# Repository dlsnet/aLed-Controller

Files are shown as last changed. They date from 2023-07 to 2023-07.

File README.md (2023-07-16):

# aLed Controller

aLed Controller is an analog leds controller for the smart home. It was designed to run with Home Assistant using ESPHome and features:

-  Six analog channels. (Can run a single CCTRGB or RGBW strip, up to two RGB strips, up to three CCT strips, or up to six single color strips with a high current and high PWM frequencies).
- Based on ESP32-WROOM-32.
- Runs EPSHome (or you can flash it with whatever firmware makes you happy)
- Changeable fuse
- [Optional] INA226 sensor (a current shunt and power monitor).
- [Optional] Ambient light sensor.
- [Optional] PCB temperature sensor (can be handy if you plan to run a high power load).
- [Optional] SHT40 temperature and humidity sensor.
- [Optional] DS18B20 temperature sensor (cheaper, easier to get hold of, and solder compared to SHT40).
- [Optional] Outputs for up to 3 external buttons.
- [Optional] I2C bus output for plugging an external sensor.
- [Optional] Connector for ePaper display.

The controller works with 5-24v input. Positive output lines are protected by a replaceable fuse.

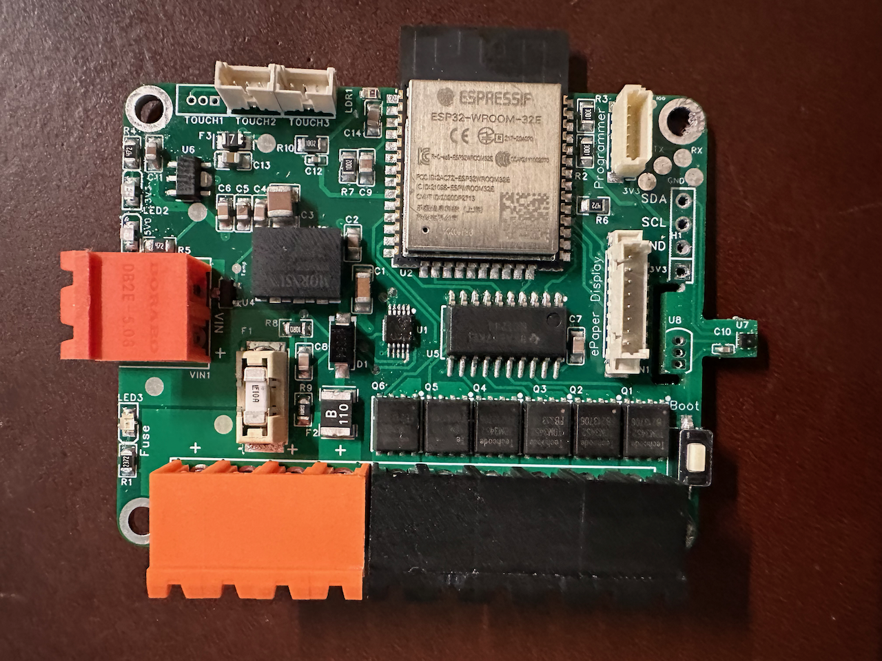
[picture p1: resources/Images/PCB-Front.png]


## PCB ordering

If you want to support the project, you can order PCB manufacturing and/or assembly on PCBWay

- [PCBWay Order](https://www.pcbway.com/project/shareproject/aLed_Controller_v2_4e3c079f.html) - they do quite necelly. Please keep in mind that stencil will be very handy.

<p align="center">
<a href="https://www.pcbway.com/project/shareproject/aLed_Controller_v2_4e3c079f.html">PCB from PCBWay</a>
  
</p>

## Enclosure

3D printed enclosure is available for the PCB. STL files can be found [here](https://github.com/dlsnet/aLed-Controller/tree/main/resources/Case%20STL)

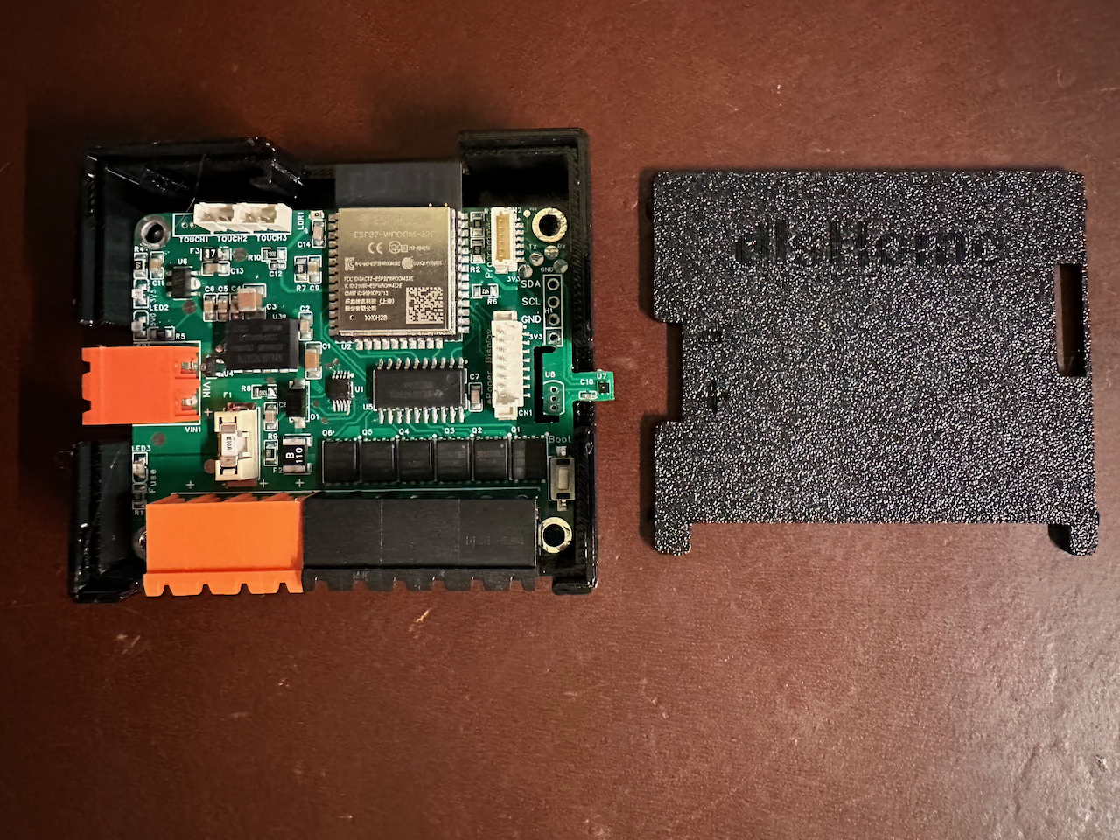
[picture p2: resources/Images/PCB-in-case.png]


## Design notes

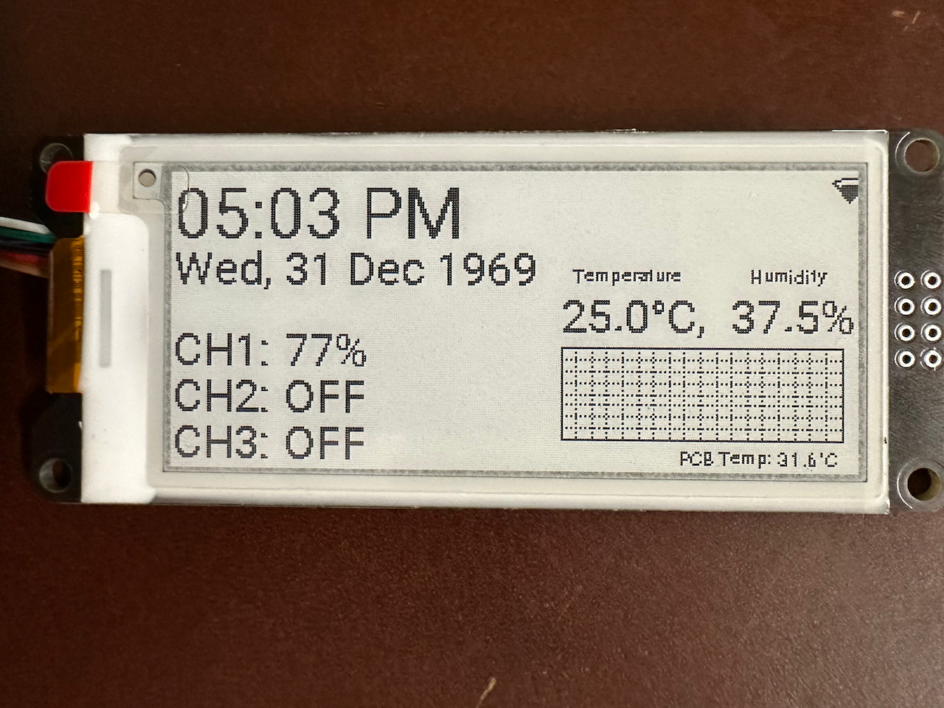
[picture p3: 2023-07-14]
resources/Images/ePaper-Display.png

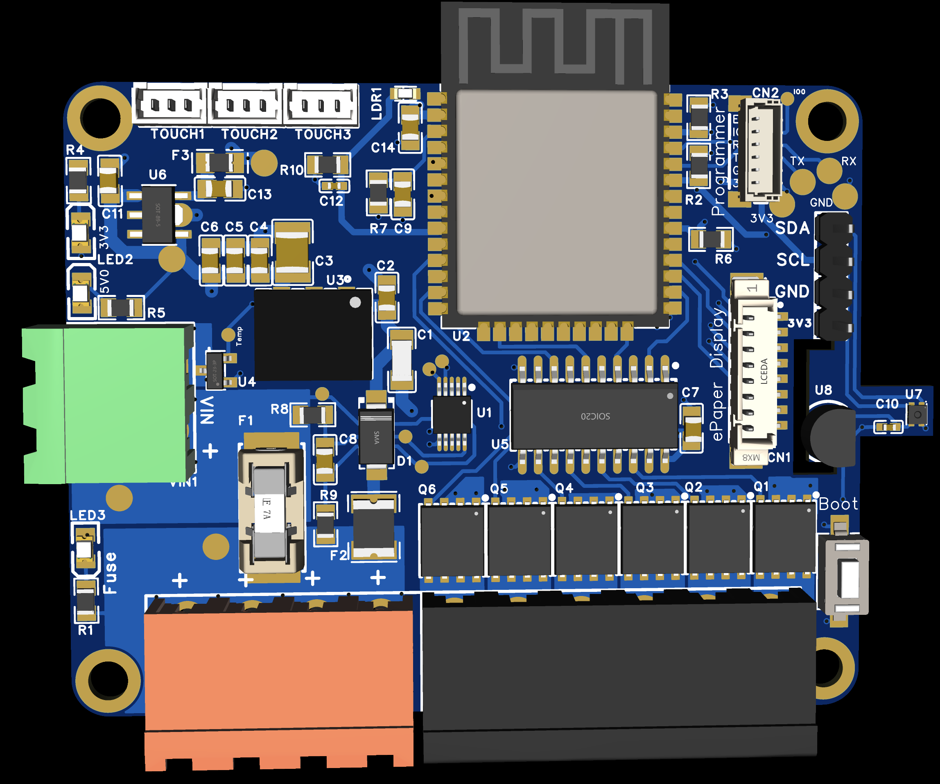
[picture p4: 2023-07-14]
resources/Images/PCB-Render-Front.png

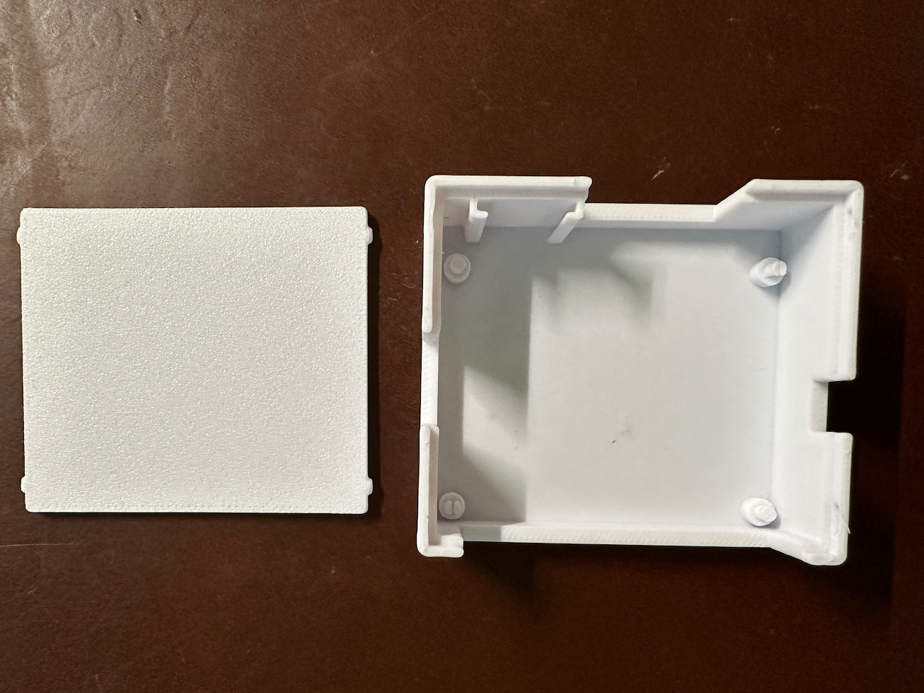
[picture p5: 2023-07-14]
resources/Images/Case.png

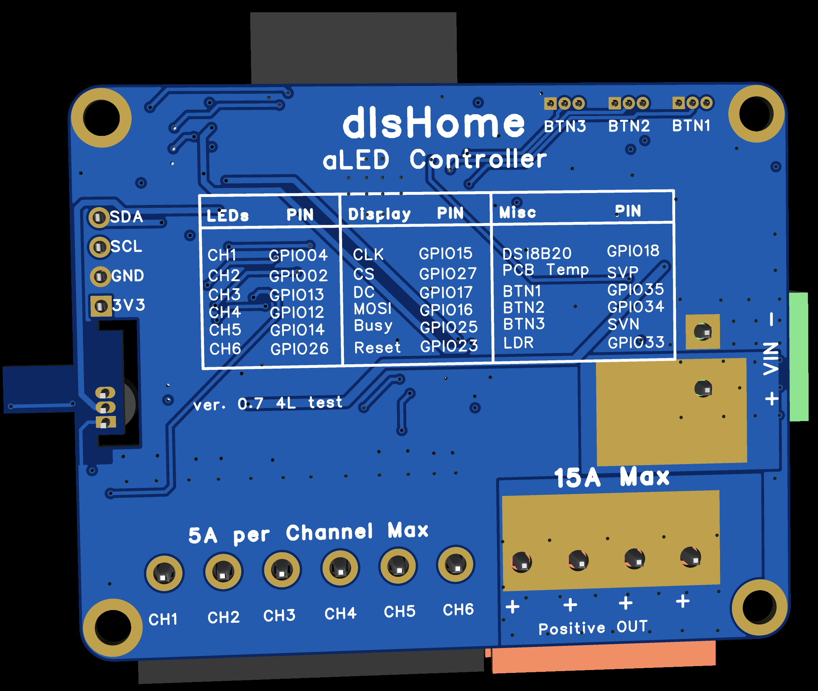
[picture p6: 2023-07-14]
resources/Images/PCB-Render-Back.png

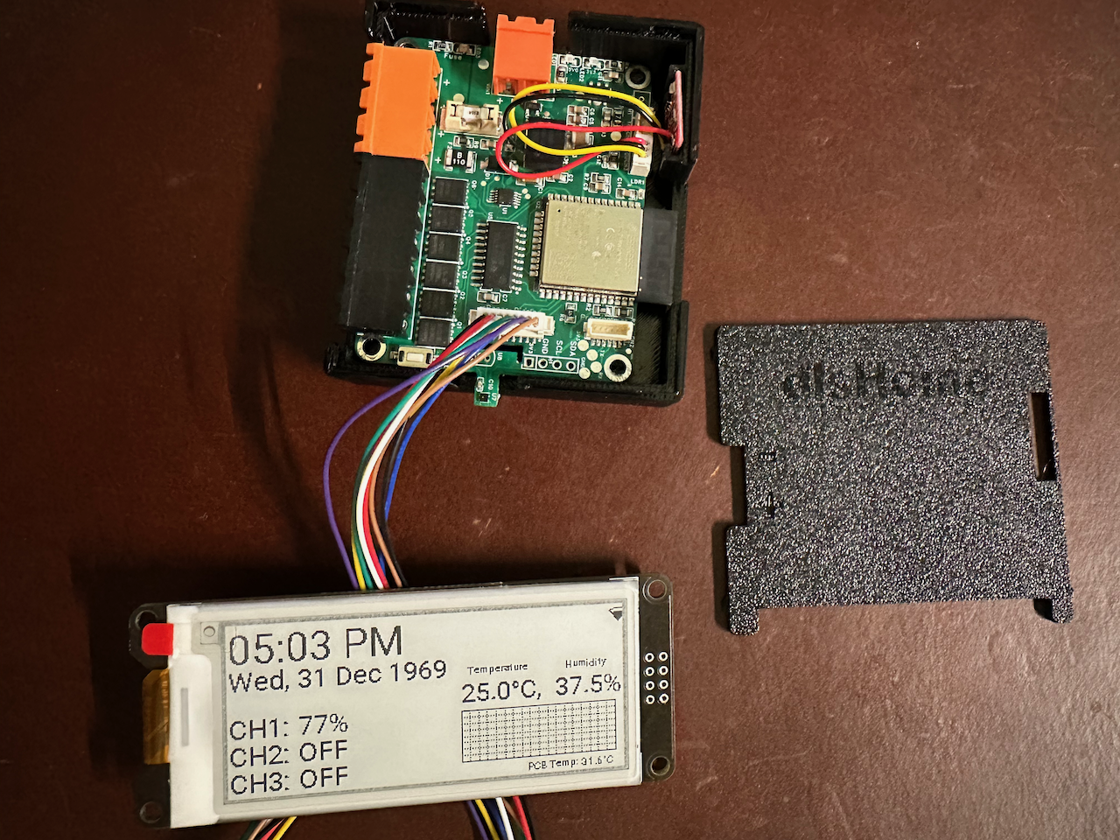
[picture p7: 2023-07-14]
resources/Images/Full-Set.png

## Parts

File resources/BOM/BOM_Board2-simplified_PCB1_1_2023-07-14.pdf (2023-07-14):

No. | Quantity | Comment | Designator | Footprint | Manufacturer Part | Supplier Part | Supplier
1 | 1 | 10uF | C1 | C1206 | CL31B106KBHNNNE | C89632 | LCSC
2 | 5 | 100nF | C2,C4,C7,C8,C14 | C0805 | TCC0805X7R104K500DT | C282732 | LCSC
3 | 1 | 47uF | C3 | C1210 | GRM32ER71A476KE15L | C84494 | LCSC
4 | 1 | 10nF | C5 | C0805 | TCC0805X7R103K500DT | C282728 | LCSC
5 | 1 | 1nF | C6 | C0805 | TCC0805X7R102M500DT C713510 | | LCSC
6 | 1 | 1uF | C9 | C0805 | CL21B105KBFNNNE | C28323 | LCSC
7 | 2 | 100nF | C10,C12 | C0402 | TCC0402X7R104K160AT | C392963 | LCSC
8 | 2 | 10uF | C11,C13 | C0805 | CL21A106KPFNNNE | C17024 | LCSC
9 | 1 | AFC12-S08CCC-00 | CN1 | CONN-SMD_8P-P1.25-V-M_AFC12-S08CCC-00AFC12-S08CCC-00 | | C395349 | LCSC
10 | 1 | JST 1mm | CN2 | CONN-SMD-6P-P1.00_BM06B-SRSS-TB-LF-SN JST 1mm | | C160392 | LCSC
11 | 1 | SS54 | D1 | SMA_L4.4-W2.8-LS5.4-R-RD | SS54 | C513478 | LCSC
12 | 1 | 01550900M | F1 | FUSE-SMD_L9.8-W5.0 | 01550900M | C108518 | LCSC
13 | 1 | BSMD1812-110-33V | F2 | F1812 | BSMD1812-110-33V | C883150 | LCSC
14 | 1 | ASMD0805-075 | F3 | F0805 | ASMD0805-075 | C135330 | LCSC
15 | 1 | OUTG | GNDOUT1 | CONN-TH_6P-P5.08_DB2ER-5.08-6P-BK | OUTG | C430467 | LCSC
16 | 1 | HDR2.54-LI-2x4P | H1 | HDR-TH_4P-P2.54-V-M | HDR2.54-LI-2x4P | C9900020145 | LCSC
17 | 1 | ALS-PT19-315C/L177/TR8 | LDR1 | SENSORS-SMD_ALS-PT19 | ALS-PT19-315C/L177/TR8 C146233 | | LCSC
18 | 1 | Power LED | LED1 | LED0805-R-RD | NCD0805O1 | C84262 | LCSC
19 | 1 | 3.3 LED | LED2 | LED0805-R-RD | NCD0805O1 | C84262 | LCSC
20 | 1 | Fuse LED | LED3 | LED0805-R-RD | NCD0805O1 | C84262 | LCSC
21 | 6 | TDM3452 | Q1,Q2,Q3,Q4,Q5,Q6 | DFN-8_L5.7-W5.1-P1.27-LS6.1-BL-2 | TDM3452 | C380223 | LCSC
22 | 1 | 23.7K | R1 | R0805 | 23.7K | C17564 | LCSC
23 | 2 | 3kΩ | R2,R3 | R0805 | 0805W8F3001T5E | C17661 | LCSC
24 | 3 | 4.7kΩ | R4,R5,R6 | R0805 | 0805W8F4701T5E | C17673 | LCSC
25 | 2 | 10kΩ | R7,R10 | R0805 | 0805W8F1002T5E | C17414 | LCSC
26 | 2 | 10Ω | R8,R9 | R0805_NEW | 0805W8F100JT5E | C17415 | LCSC
27 | 1 | Boot | SW1 | SW-SMD_L6.0-W3.5-LS8.0 | Boot | C2888456 | LCSC
28 | 1 | Touch 1 | TOUCH1 | CONN-TH_3P-P1.25_CAX_1.25-3A | Touch 1 | C722597 | LCSC
29 | 1 | Touch 2 | TOUCH2 | CONN-TH_3P-P1.25_CAX_1.25-3A | Touch 2 | C722597 | LCSC
30 | 1 | Touch 3 | TOUCH3 | CONN-TH_3P-P1.25_CAX_1.25-3A | Touch 3 | C722597 | LCSC
31 | 1 | INA226AIDGSR | U1 | MSOP-10_L3.0-W3.0-P0.50-LS5.0-BL-dla | INA226AIDGSR | C49851 | LCSC
32 | 1 | ESP32-WROOM-32E-N8 | U2 | WIFI-SMD_ESP32-WROOM-32E | ESP32-WROOM-32E-N8 | C701342 | LCSC
33 | 1 | K7805MT-1000R4 | U3 | PWRM-SMD_K78XXMT-1000R4 | K7805MT-1000R4 | C2692189 | LCSC
34 | 1 | MCP9700AT-E/TT | U4 | SOT-23-3_L2.9-W1.3-P1.90-LS2.4-BR | MCP9700AT-E/TT | C127949 | LCSC
35 | 1 | SN74HCT244NSR | U5 | SOIC-20_L13.3-W5.5-P1.27-LS7.8-BL | SN74HCT244NSR | C6777 | LCSC
36 | 1 | ME6217C33P5G | U6 | SOT-89-5_L4.5-W2.5-P1.50-LS4.5-BR | ME6217C33P5G | C81592 | LCSC
37 | 1 | SHT40-AD1B-R2 | U7 | DFN-4_L1.5-W1.5-P0.8-TL-EP-dls | SHT40-AD1B-R2 | C2909890 | LCSC
38 | 1 | DS18B20 | U8 | TO-92-3_L4.9-W3.7-P1.27-L | DS18B20 | C376006 | LCSC
39 | 1 | LINE IN | VIN1 | CONN-TH_2P-P5.08_XY2500R-D5.08-2P | XY2500R-D-5.08-2P | C505824 | LCSC
40 | 1 | OUT | VINOUT1 | CONN-TH_4P-P5.08_DB2ER-5.08-4P-OG | OUT | C430449 | LCSC

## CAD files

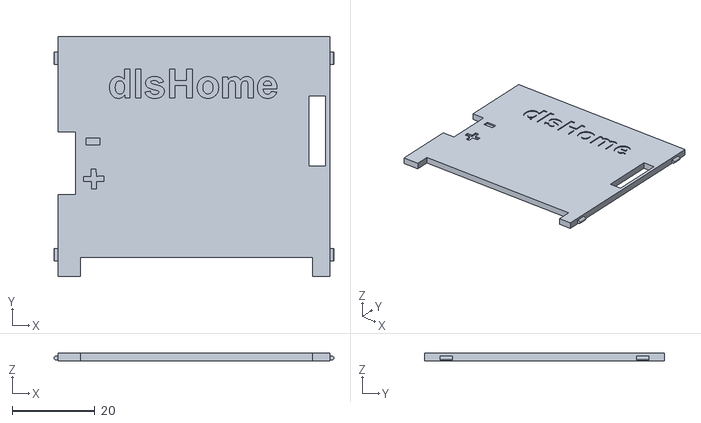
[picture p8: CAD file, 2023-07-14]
resources/Case STL/PCB_Box_Lid.stl
67.7 x 58.0 x 2.00

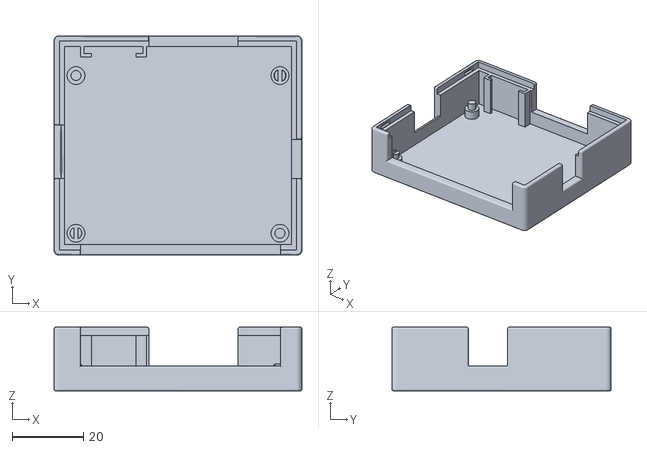
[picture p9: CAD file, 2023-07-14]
resources/Case STL/PCB_Box_Base.stl
69.6 x 61.6 x 17.9

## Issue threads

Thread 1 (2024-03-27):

Missing schematic file

Pace17881, 2024-03-27:
Hi,

Thanks for the cool design.

I would like to add some pins to your design, to have the ability to connect digital leds like SK6812.

Could you provide the schematic file please?

Thanks in advance

bg
sebastian

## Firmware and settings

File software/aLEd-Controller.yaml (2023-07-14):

substitutions:
  name: cct-led-test
  devicename: "cct-led-test"
  friendly_name: "cct-led-test"
  long_devicename: "cct-led-test Analog LED controller (ESP32) Device"

esphome:
  name: ${name}

external_components:
  - source: github://pr#4579
    components: [waveshare_epaper]

esp32:
  board: esp32dev
  framework:
    type: arduino

wifi:
  ssid: !secret wifi_ssid
  password: !secret wifi_password
  power_save_mode: none
  #domain: .local

  ap:
    ssid: "$devicename Fallback"
    password: !secret wifi_password

web_server:
  port: 80


captive_portal:

logger:

dallas:
  - pin: GPIO18

api:

time:
  - platform: homeassistant
    id: homeassistant_time

font:

  - file: "gfonts://Roboto"
    id: font1
    size: 20

  - file: "gfonts://Roboto"
    id: font_large
    size: 30

  - file: "gfonts://Roboto"
    id: font_small
    size: 8

  - file:
      type: gfonts
      family: Roboto
      weight: 900
    id: font2
    size: 16

  # Include Material Design Icons font
  # It should be saved to config/esphome/fonts folder

  - file: 'fonts/materialdesignicons-webfont.ttf'
    id:  mdi_wifi
    size: 15
    glyphs:
      - "\U000F092B" # mdi-wifi-strength-alert-outline
      - "\U000F091F" # mdi-wifi-strength-1
      - "\U000F0922" # mdi-wifi-strength-2
      - "\U000F0925" # mdi-wifi-strength-3
      - "\U000F0928"  # mdi-wifi-strength-4


color:
  - id: my_light_red
    red: 100%
    green: 20%
    blue: 25%
    white: 0%

graph:
  # Show bare-minimum auto-ranged graph
  - id: temperature_graph
    duration: 24h
    x_grid: 10min
    y_grid: 1.0
    width: 120
    height: 40
    traces:
      - sensor: pcb_temp
        line_type: DOTTED
        line_thickness: 2
      - sensor: sht40_temp
        line_type: SOLID
        line_thickness: 3


i2c:
  sda: 21
  scl: 22
  scan: true

# Setup SPI

spi:
  clk_pin: 15
  mosi_pin: 16

# Configuration for the display
display:
  - platform: waveshare_epaper
    model: 2.90inv2
    id: eink_display
    cs_pin: 27
    dc_pin: 17
    busy_pin: 25
    reset_pin: 23
    full_update_every: 90
    rotation: 270°
    lambda: |-
      it.strftime(1, 1, id(font_large), "%I:%M %p ", id(homeassistant_time).now());
      it.strftime(1, 30, id(font1), "%a, %d %b %Y", id(homeassistant_time).now());
      it.printf(175, 40, id(font_small), "Temperature");
      it.printf(250, 40, id(font_small), "Humidity");
      it.printf(170, 50, id(font1), "%.1f°C,  %.1f%%", id(sht40_temp).state, id(sht40_hum).state);
      it.graph(170, 75, id(temperature_graph));
      it.printf(220, 117, id(font_small), "PCB Temp: %.1f°C", id(pcb_temp).state);
      it.printf(1, 65, id(font1), "CH1: ");
      it.printf(1, 85, id(font1), "CH2: ");
      it.printf(1, 105, id(font1), "CH3: ");

      it.printf(50, 65, id(font1),  "%s", id(light1_br).state.c_str() );
      it.printf(50, 85, id(font1),  "%s", id(light2_br).state.c_str() );
      it.printf(50, 105, id(font1),  "%s", id(light3_br).state.c_str() );

      /* WiFi Signal Strenght */
      if(id(wifisignal).has_state()) {
        int x = 288;
        int y = 15;
        if (id(wifisignal).state >= -50) {
            //Excellent
            it.print(x, y, id(mdi_wifi), TextAlign::BASELINE_CENTER, "\U000F0928");
            //ESP_LOGI("WiFi", "Exellent");
        } else if ( (id(wifisignal).state  >= -60) && (id(wifisignal).state  < -50) ) {
            //Good
            it.print(x, y, id(mdi_wifi), TextAlign::BASELINE_CENTER, "\U000F0925");
            //ESP_LOGI("WiFi", "Good");
        } else if ( (id(wifisignal).state  >= -75) && (id(wifisignal).state  < -60) ) {
            //Fair
            it.print(x, y, id(mdi_wifi), TextAlign::BASELINE_CENTER, "\U000F0922");
            //ESP_LOGI("WiFi", "Fair");
        } else if ( (id(wifisignal).state  >= -100) && (id(wifisignal).state  < -75) ) {
            //Weak
            it.print(x, y, id(mdi_wifi), TextAlign::BASELINE_CENTER, "\U000F091F");
            //ESP_LOGI("WiFi", "Weak");
        } else {
            //Unlikely working signal
            it.print(x, y, id(mdi_wifi), TextAlign::BASELINE_CENTER, "\U000F092B");
            //ESP_LOGI("WiFi", "Unlikely");
        }
      }
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

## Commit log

2023-07-14 Added initial greber and BOM
    [BOM_Board2-simplified_PCB1_1_2023-07-14.xlsx]
2023-07-14 added yaml code
    [aLEd-Controller.yaml]
2023-07-14 added case stl files
    [PCB_Box_Base.stl, PCB_Box_Lid.stl]
2023-07-15 readme updated with PCBWay link
